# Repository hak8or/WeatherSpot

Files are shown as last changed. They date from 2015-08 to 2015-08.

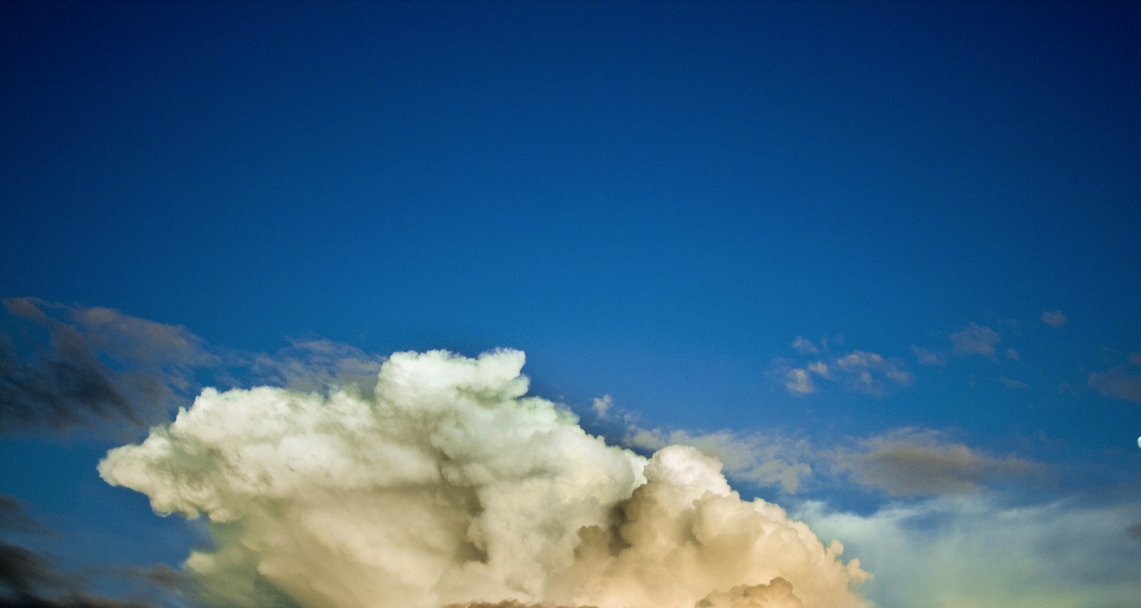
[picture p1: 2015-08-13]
Website/pic/sky_background.jpeg

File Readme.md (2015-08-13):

## WeatherSpot

A weather reporting ecosystem consisting of a website, windows native application, and multiple weather sensors to fetch weather data.

### Development
1. Login to the WeatherSpot server using ```ssh root@WeatherSpot.us```.
2. Make sure the influx database is running using ```docker ps -a``` to see active containers. If it's not running, a ```docker start weather_db``` will get it up again.
3. Do whatever you need to do.

In the event the influxdb container was removed, the following will get it up again:
```bash
docker run -d -p 8083:8083 -p 8084:8084 -p 8086:8086 -e PRE_CREATE_DB="weather" --name weather_db tutum/influxdb:latest
```

### Docker Installation
```bash
# Have to use this script since the official repo has an outdated (v1.5) docker.
wget -qO- https://get.docker.com/ | sh

# Unmasks the services.
systemctl unmask docker.service
systemctl unmask docker.socket

# And starts them.
systemctl start docker.service
systemctl start docker.socket
```

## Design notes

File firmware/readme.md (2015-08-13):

## Firmware for Weatherstation

Using an ESP8266 for communication over wifi to our backend hosted on digital ocean, log and send weather data to the "cloud".

### Doxygen docs
Running ```doxygen doxygen_config``` suffices.

### Compiling
Make sure to install the following libraries:
- DHT Sensor Library by Adafruit (Version 1.1.1)
- Sparkfun MPL3115A2 by Sparkfun (Version 1.2.0)
- TimerOne by Jesse (Version 1.1.0)

Afterwards, simply compiling suffices.

### Configuration
There are only three defines in ```firmware.ino``` which need to be modified,
- SSID (SSID of the wifi network you want to connect to)
- password (Password of the wifi you want to connect to)
- location (Name of the dataseries you want to send data too)

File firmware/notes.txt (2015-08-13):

Make a sensors struct or class to hold all our sensor data which will be used for JSON data sent to our server.

AT+UART_DEF=9600,8,1,0,0
AT+UART_CUR=9600,8,1,0,0
AT+RST
AT+CWMODE=1
AT+CWJAP="OpenWrt","castle2004"
AT+CIFSR
AT+GMR

00170901

http://www.electrodragon.com/w/ESP8266
http://www.rei-labs.net/esp8266-connecting-to-internet/
http://electronut.in/an-iot-project-with-esp8266/
http://mcuoneclipse.com/2014/12/14/tutorial-iot-datalogger-with-esp8266-wifi-module-and-frdm-kl25z/
https://github.com/espressif/esp8266_at/wiki/TCPIP_at_0019000902
http://www.instructables.com/id/Blink-for-ESP8266-native-like-arduino-using-Window/step2/Upload-latest-firmware-SDK/
https://www.youtube.com/watch?v=QkZrrydLw-8
http://bbs.espressif.com/viewtopic.php?f=5&t=680
http://www.esp8266.com/viewtopic.php?f=6&t=1428
http://blog.electrodragon.com/cloud-updating-your-wi07c-esp8266-now/
http://tech.scargill.net/esp8266-busy-s/
http://tomeko.net/other/ESP8266/
http://kacangbawang.com/latest-at-firmware-for-esp8266-with-512k-flash/
https://github.com/pfalcon/esp-open-sdk

=========================
I have been fumbling around with trying to update my SFP module from "00170901" (AT-thinker Firmware) as given by "AT+GMR".

I tried to update using "AT+CIUPDATE" but got an Error after the fourth step instead of OK, so I tried to do it manually using flash_download_tool_v1.2_150512, but I fear I really botched things up since now I get a "MEM CHECK FAIL" from the module, and pressing enter after a command using Putty just puts the cursor back at the beginning of the line instead of executing the command (such as AT+GMR).

I have attempted to flash the firmware using the most recent SDK (esp_iot_sdk_v1.2.0_15_07_03) as per [this](https://www.youtube.com/watch?v=QkZrrydLw-8) video, but I afterwards began to receive the memcheck error. I also attempted to flash the module as per the directions in the SDK readme but still same issue. I fear I probably overwrote some critical sections of flash and before botching things up further, I wanted to make sure I have an up to date resource.

So, does anyone know what files go to what locations from the most recent SDK so I can get my SFP-01 back up and running? Assume that I overwrote the entire flash with 0's, so I am starting from scratch. I wasn't sure if I should have posted this here or on the official [here](http://bbs.espressif.com/viewtopic.php?f=5&t=680).
=====================

### How to manually flash new SDK
esp_iot_sdk_v1.2.0\bin\at\eagle.flash.bin         0x00000
esp_iot_sdk_v1.2.0\bin\at\eagle.irom0text.bin     0x40000
esp_iot_sdk_v1.2.0\bin\blank.bin                  0x3e000
esp_iot_sdk_v1.2.0\bin\blank.bin                  0x7e000
esp_iot_sdk_v1.2.0\bin\esp_init_data_default.bin  0xFC000
26 Mhz crystal
40 MHZ SPI speed, Quad I/O, 4 megabit (SpiAutoSet probably does this automatically, need to check)
Now running at 115200 default, need to reset to lower speed because softserial sucks butt and can't keep up that fast. Reset to 9600 baud via AT+UART_DEF=9600,8,1,0,0

Also, putty does not offer to do a proper carriage return, so press enter and then ctrl-j after every command if you need to use putty. Suprisingly enough, the Arduino serial monitor has an option for newline and carriage return which works correctly.
http://comp.terminals.narkive.com/K5YqczS3/i-want-putty-to-send-a-linefeed-and-carriage-return-everytime-i-press-cr

### Output of GMR now.
AT+GMR

AT version:0.30.0.0(Jul  3 2015 19:35:49)
SDK version:1.2.0
compile time:Jul  3 2015 20:52:41

Pinout of wifi module:
TX -> RX
RX -> TX
CH_PD -> 3v3
VCC -> 3v3
GND -> GND
RST -> OPEN

pull RST down only for a second and let go, it will restart the module

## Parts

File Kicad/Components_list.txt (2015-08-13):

Components list

1. MPL3115A2 - Freescale Altimeter/pressure sensor. Digikey reference: MPL3115A2-ND. Price: $3.29 per unit
2. DHT11 - Digital Humidity Temperature Sensor. Price: $7.49 for 4 pieces
3. Light sensor. Price: free
4. Atmega328p - Main microcontroller Price: free
5. MCP1802 - Voltage Regulator - Digikey reference: MCP1802T-3302I/OTCT-ND. Price: free
6. Other - Subcomponents such as capacitors or resistors. Price: free
7. ESP8266 - Wifi module. Price:~$6? per unit

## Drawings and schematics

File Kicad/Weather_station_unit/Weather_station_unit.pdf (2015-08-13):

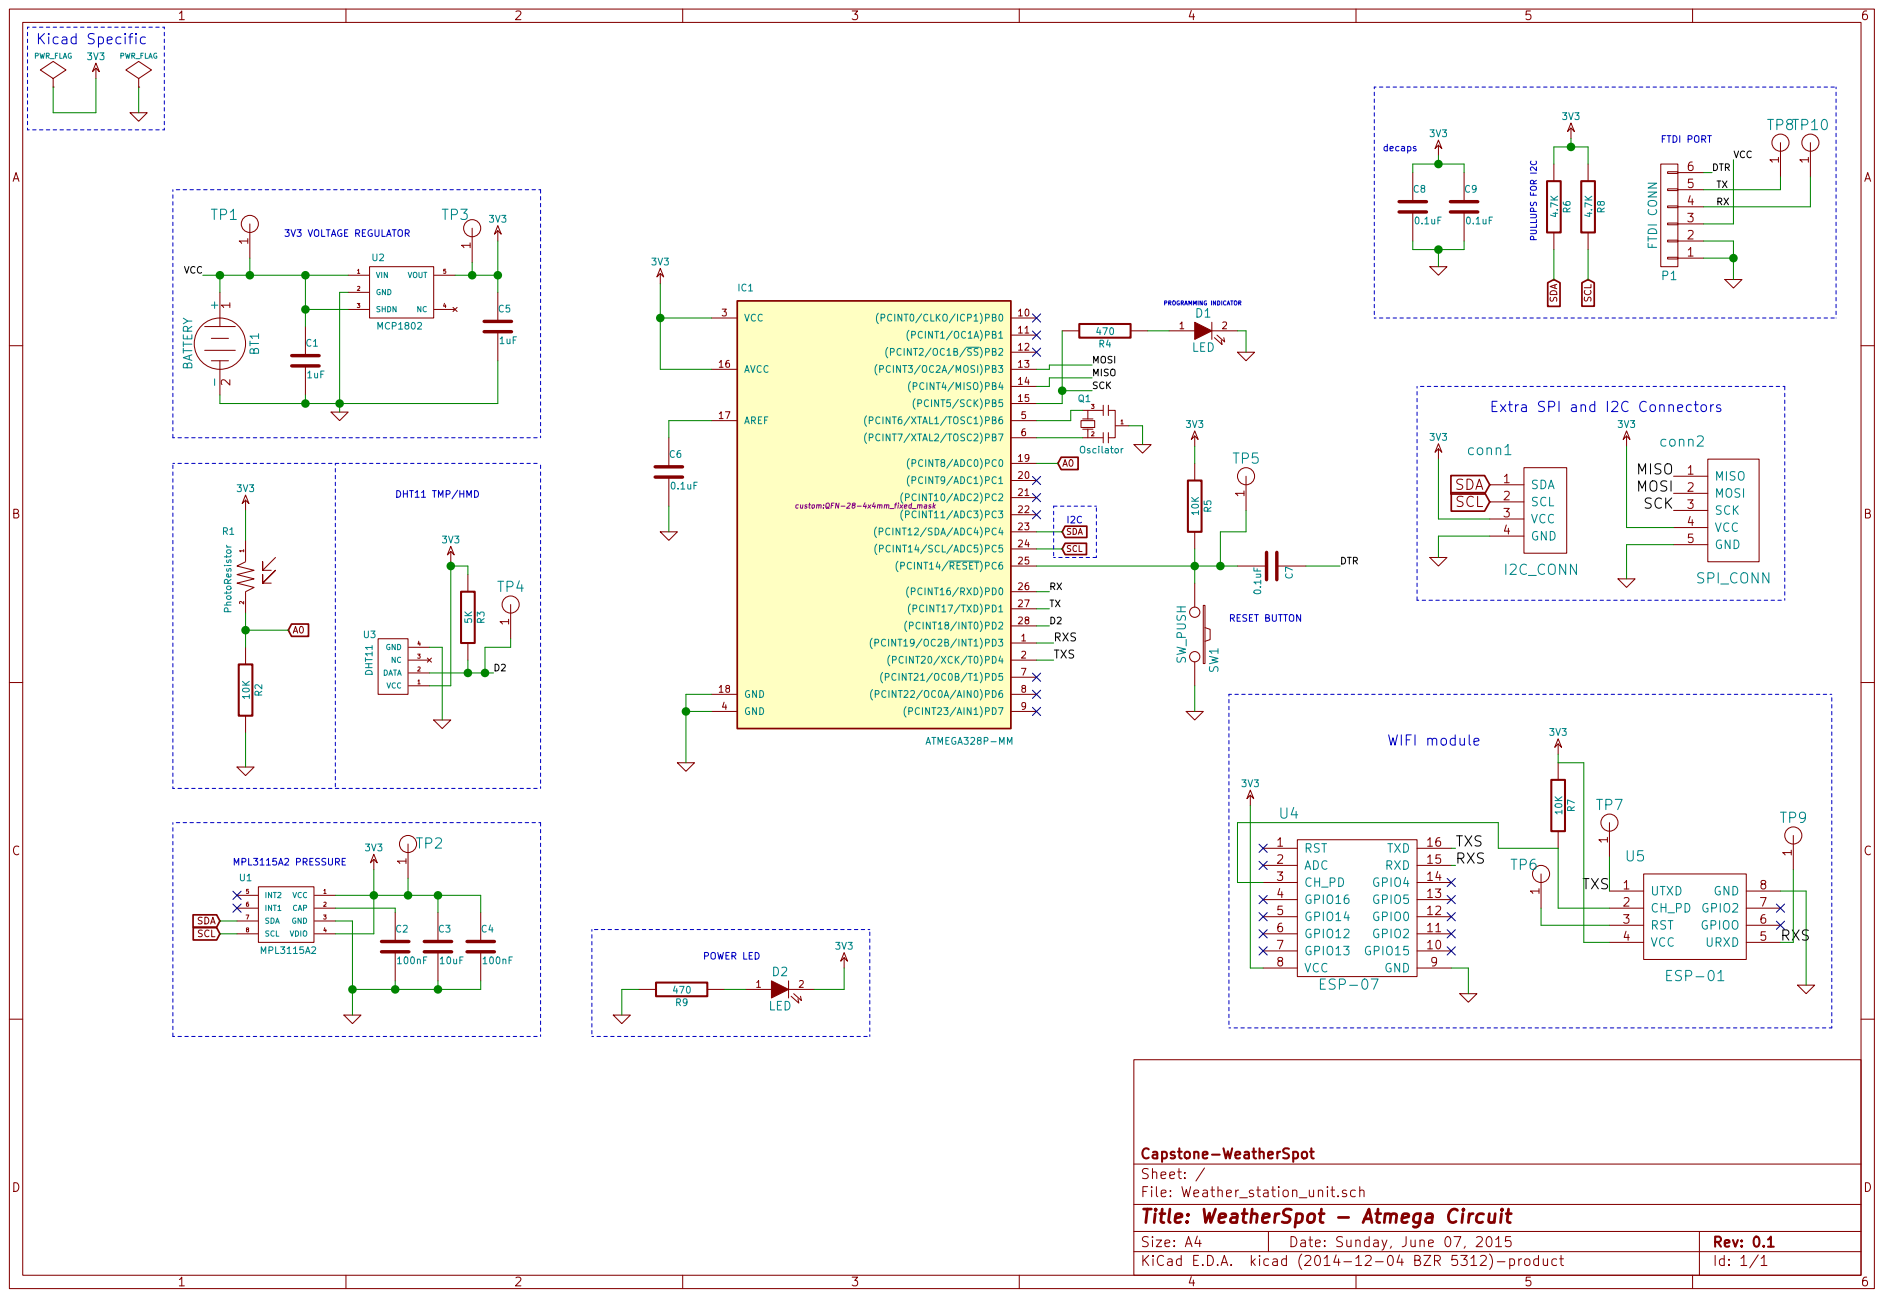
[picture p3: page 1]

1 TP10 MISO 1 MOSI 2 SCK 3 VCC 4 GND 5 conn2SPI_CONN
FTDI PORT

File: Weather_station_unit.sch Sheet: / Capstone-WeatherSpot

Id: 1/1 Title: WeatherSpot - Atmega Circuit

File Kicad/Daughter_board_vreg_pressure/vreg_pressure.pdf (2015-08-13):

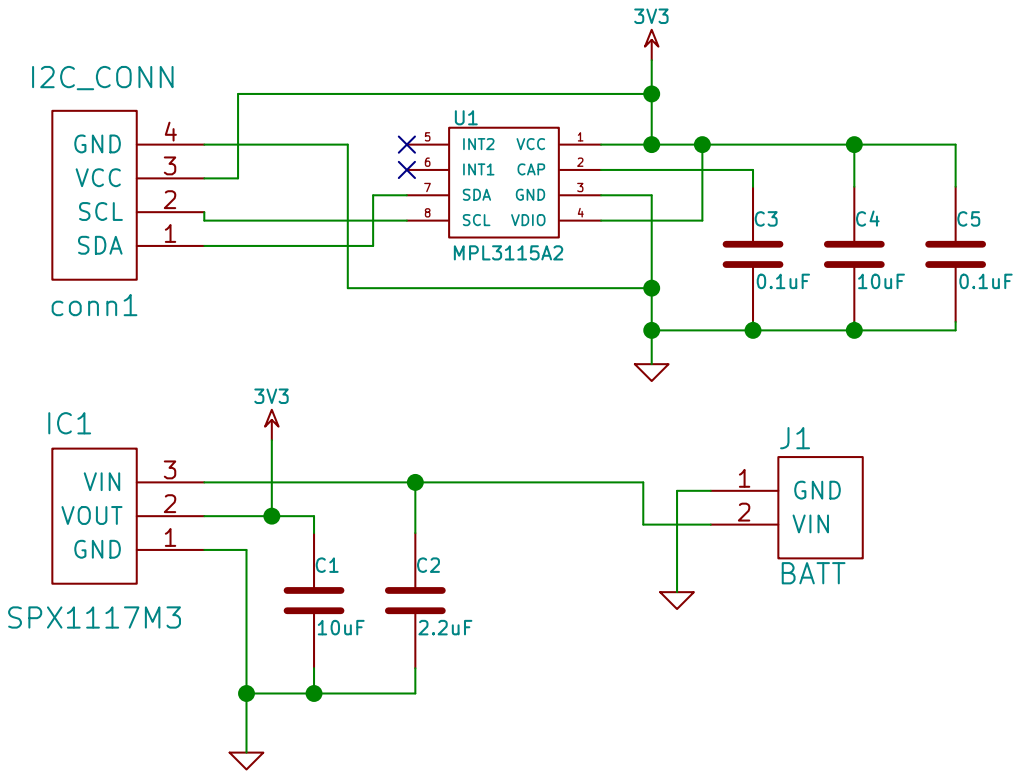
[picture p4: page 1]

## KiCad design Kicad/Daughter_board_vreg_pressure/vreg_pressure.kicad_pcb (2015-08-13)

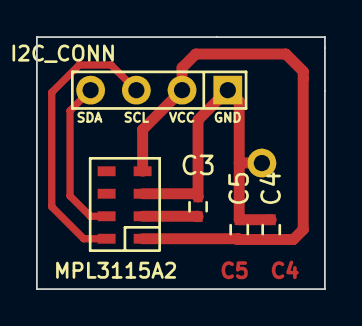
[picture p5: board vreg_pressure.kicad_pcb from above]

Board: 2 copper layers, 16.0 x 14.0 mm, 6 parts (0 on the bottom side), 5 nets.

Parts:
C3, C5: 0.1uF; C_0402
C4: 10uF; C_0402
U1: MPL3115A2
VIA_HOME_ETCH: VAL**; VIA_HOME_ETCH
conn1: I2C_CONN

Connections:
3V3: C4.1, C5.1, U1.1, U1.4, conn1.3
GND: C3.2, C4.2, C5.2, U1.3, VIA_HOME_ETCH.1, conn1.4
unnamed: C3.1, U1.2
unnamed: U1.7, conn1.1
unnamed: U1.8, conn1.2

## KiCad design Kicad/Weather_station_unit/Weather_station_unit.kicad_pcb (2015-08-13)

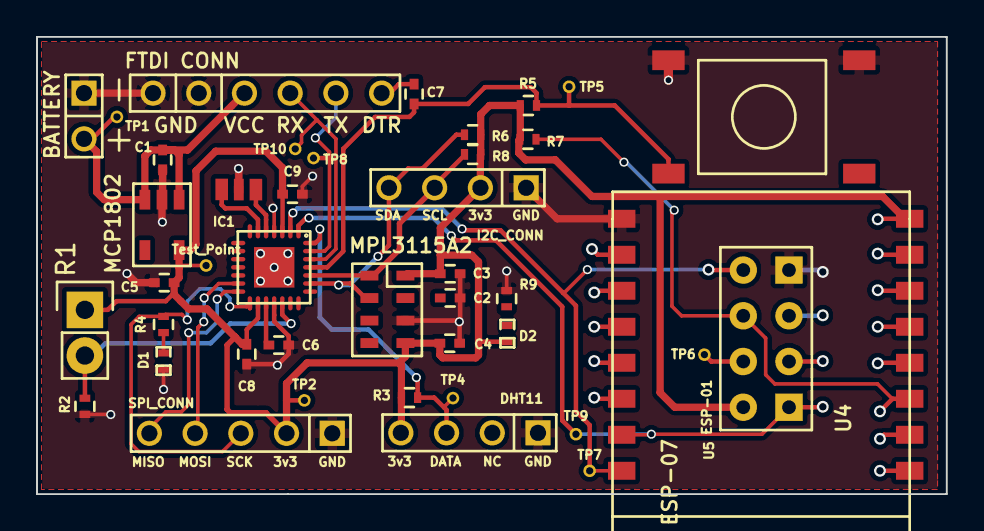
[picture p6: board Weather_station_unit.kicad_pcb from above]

Board: 2 copper layers, 50.5 x 25.4 mm, 42 parts (0 on the bottom side), 24 nets.

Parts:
BT1: BATTERY; BATT_CONN
C1, C5: 1uF; C_0402
C2, C4: 100nF; C_0402
C3: 10uF; C_0402
C6, C7, C8, C9: 0.1uF; C_0402
D1, D2: LED; SMD-0402_LED
IC1: ATMEGA328P-MM; QFN-28-4x4mm_fixed_mask
P1: FTDI CONN; FTDI_PORT
Q1: Oscilator; ceramic_resonator_smd
R1: PhotoResistor; Socket_Strip_Straight_1x02
R2, R5, R7: 10K; R_0402
R3: 5K; R_0402
R4, R9: 470; R_0402
R6, R8: 4.7K; R_0402
SW1: SW_PUSH; push_switch_SMD
TP1: TP1; TEST_POINT
TP2: TP2; TEST_POINT
TP3: Test_Point; TEST_POINT
TP4: TP4; TEST_POINT
TP5: TP5; TEST_POINT
TP6: TP6; TEST_POINT
TP7: TP7; TEST_POINT
TP8: TP8; TEST_POINT
TP9: TP9; TEST_POINT
TP10: TP10; TEST_POINT
U1: MPL3115A2
U2: MCP1802; MCP1802T
U3: DHT11
U4: ESP-07
U5: ESP-01
conn1: I2C_CONN
conn2: SPI_CONN

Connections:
3V3: C3.1, C4.1, C5.1, C8.1, C9.1, D2.2, IC1.3, IC1.16, R1.1, R3.1, R5.1, R6.1, R7.1, R8.1, TP2.1, TP3.1, U1.1, U1.4, U2.5, U3.1, U4.8, U5.4, conn1.3, conn2.4
/D2: IC1.28, R3.2, TP4.1, U3.2
/DTR: C7.1, P1.6
/MISO: IC1.14, conn2.1
/MOSI: IC1.13, conn2.2
/RX: IC1.26, P1.4, TP10.1
/RXS: IC1.1, TP9.1, U4.15, U5.5
/SCK: IC1.15, R4.2, conn2.3
/TX: IC1.27, P1.5, TP8.1
/TXS: IC1.2, TP7.1, U4.16, U5.1
/VCC: BT1.1, C1.1, P1.3, TP1.1, U2.1, U2.3
A0: IC1.19, R1.2, R2.1
GND: BT1.2, C1.2, C2.2, C3.2, C4.2, C5.2, C6.2, C8.2, C9.2, D1.2, IC1.4, IC1.18, P1.1, P1.2, Q1.1, R2.2, R9.2, SW1.2, U1.3, U2.2, U3.4, U4.9, U5.8, conn1.4, conn2.5
unnamed: C2.1, U1.2
unnamed: C6.1, IC1.17
unnamed: C7.2, IC1.25, R5.2, SW1.1, TP5.1
unnamed: D1.1, R4.1
unnamed: D2.1, R9.1
unnamed: IC1.5, Q1.3
unnamed: IC1.6, Q1.2
unnamed: R7.2, U4.3, U5.2
unnamed: TP6.1, U5.3
SCL: IC1.24, R8.2, U1.8, conn1.2
SDA: IC1.23, R6.2, U1.7, conn1.1

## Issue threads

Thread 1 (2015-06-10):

Add breakout for I2C, SPI, and UART on the PCB

hak8or, 2015-06-10:
For Kicad @glina126

glina126, 2015-06-11:
will do, as well as test points.

hak8or, 2015-06-11:
Just a cool thing, if you reference this in your commit, like
```bash
git commit -m "Added breakouts as per issue #1"
```

then the commit will be referenced in here. :sunglasses: And if you do ```bash fixes issue #1``` then it will even close the issue!

Closed 2015-06-11.

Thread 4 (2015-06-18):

Breakout GPIO 0 + 2 from wifi modules and 2 interrupt capable pins on Atmega

hak8or, 2015-06-18:
Considering issues regarding timers in hak8or@aeff93bcb327e73d56c7c01b92e3bbc12f4005ce, I feel it would be a good idea to break out two of the GPIO from the Wifi board and Arduino in the event the Arduino timers will be problamatic so we can still have the ability to generate timer based interrupts.

Since pulling down GPIO2 on the wifi module will cause it to enter firmware update mode, I recommend that the pins be just broken out in the form of a pair of 2 male headers.

hak8or, 2015-06-18:
The arduino people put the friggen onboard LED on the same pin as the SPI clock, so nevermind about the reason.

Though, it would be a good idea to break out two of the pins anyways if things go bad, especially from the Atmega at least considering it's a QFN.

Closed 2015-07-07.

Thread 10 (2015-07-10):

Create Custom Google Map Markers showing current condition and temperature values.

pl12133, 2015-07-10:
Example would be sunny, cloudy, raining, and fair condition icons with numbers over them.

I've got some basic ugly looking labels, [described here](http://blog.mridey.com/2009/09/label-overlay-example-for-google-maps.html), attached to the images now, it will take some styling to make them look decent. It might not be a great solution but its a start.

Closed 2015-12-18.

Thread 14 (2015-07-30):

Make responsive for Android

ple1213, 2015-07-30:
Responsive on desktop browser and apple but not on android.

http://stackoverflow.com/questions/12021794/android-browser-ignores-responsive-web-design

pl12133, 2015-08-01:
I've added few changes, give it a try on your Android devices now.
*Change 1*: Added a "min-height:100%" tag to html and body tags in `css/main_page.css`
*Change 2*: Set two content headers in our index.html.
`1 <meta content="True" name="HandheldFriendly">`
`2 <meta name="viewport" content="width=device-width, initial-scale=1.0, maximum-scale=1.0, user-scalable=0">`

The result is a background that seems to consistently fill the Viewport in both portrait and landscape on mobile devices.

I used http://www.cssmediaqueries.com and saw my device had a scale of 1.5, that was causing the scrollbars happening on Android devices. That stack overflow thread was very helpful, but has a little sillyness going on; Stefan K posts his answer of:
`1 <meta content="True" name="HandheldFriendly">`
`2 <meta name="viewport" content="width=device-width, initial-scale=1.0, maximum-scale=1.0, user-scalable=0">`
`3 <meta name="viewport" content="width=device-width">`

Line 1 and line 2 are the solution we need, and line 3 overwrites line 2, so removing line 3 provides us with the fix that we need. Fixing the scale back to 1.0 seems to fix the issue, but I'm not sure if changing scale like this has any other implications for our site.

Please test on any devices you have and see if these changes are in line with the goal of 'Responsive Web Design'

ple1213, 2015-08-04:
Works ok

hak8or, 2015-08-04:
Glorious, working here too. Though, one suggestion would be to remove the border around the graphs in the graph page. Since on my nexus 5 the graphs and whatnot get cut off.

[Imgur](http://i.imgur.com/jm0p3Rf.jpg)

hak8or, 2015-08-04:
Oh ffs the link doesn't seem to work, so here is the direct link. http://i.imgur.com/jm0p3Rf.jpg

Closed 2015-08-04.

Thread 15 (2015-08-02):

Heartbeat - messes up light readings

glina126, 2015-08-02:
The heartbeat, as great as it is, it is working against us here.

1, its using power - not much, but still. three hour battery life is not too long...
2. it is offsetting the light measurements.

Solution:
- reduce the blink rate
- blink only when not measuring the light intensity

hak8or, 2015-08-02:
The power consumption of heart beat is very low. I wouldn't even think about power consumption untill we can put the wifi module to sleep.

But what we could do is actually have it blink maybe once every 5 seconds with a 5% duty cycle or something like that. The chances of the light reading happening while the LED is active is 5% which is pretty small. Or continue at the speed now but make the duty cycle much smaller which would lead the same result.

glina126, 2015-08-02:
I am trying out disconnecting the wifi module from the AP, I will run a test to see if that helps preserve power.

hak8or, 2015-08-02:
Meaning the ```AT+CWQAP``` command? Did you try out the sleep command yet with the soldering fix?

Also, for sleep, to save you googling, it's ```AT+GSLP=500``` to make it sleep 500 milliseconds and then wake up by itself and start the ESP module again from scratch (just like after a reset state). But you have to solder "XPD_DCDC with EXT_RSTB via 0R" for this to work.

glina126, 2015-08-02:
yea i am doing the CT+CWQAP command for now. I will see how long this lives first. then I will try the AT+GSLP command - I really dont want to mess with soldering on the unit.

hak8or, 2015-08-02:
Soldering would be just shorting one of [these two pads](https://goo.gl/photos/3yqcSUxmTnHtEDG38) though (SMD module).

hak8or, 2015-08-07:
Alright, so I just flashed my board with the new firmware and will let it run for an hour and see how the light readings are. If it's good, I guess we can close this.

hak8or, 2015-08-10:
Closed since the heartbeat led is now disabled during sensor readings.

Closed 2015-08-10.

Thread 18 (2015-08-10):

Locations.html doesnt work properly

glina126, 2015-08-10:
locations.html has very strange spacing and it does not clear the old graphs when you switch to a new one. Instead it appends more and more graphs on the bottom with huge spacing.

pl12133, 2015-08-10:
That sounds like a broken version that I was working on but it has since been fixed, can you make sure that's not a cached copy? It was unstable like that before but `locations.html` should be working now.

hak8or, 2015-08-10:
Working totally fine on my end when mobile. I never noticed any spacing issues earlier, or that graphs were appended instead of replaced for locations.html

pl12133, 2015-08-13:
Fixed.

Closed 2015-08-13.

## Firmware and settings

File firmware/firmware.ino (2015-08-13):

// Gotta include this because the arduino IDE does some magic including nonsense.
#include <SoftwareSerial.h>
#include <Wire.h>

// Includes relevant to our project.
#include "Sensors.h"
#include "Heartbeat.h"
#include "Network.h"
#include "DHT.h"
#include <TimerOne.h>
#include "SparkFunMPL3115A2.h"

// Global because arduno says we need setup and loop functions.
Network network;
Sensors sensors;

// Defines for our wifi credentials.
#define SSID "OpenWrt"
#define password "castle2004"

// Defines what location (Series) we will be sending our data too.
#define location "Queens"

/**
 * @brief The main setup loop for our sensors and WIFI.
 */
void setup(){
	// Start up the serial communication.
	Serial.begin(115200);

	// Dump a decent header to our console.
	Serial.println(F("=================================================="));
	Serial.println(F("\t WeatherSpot firmware Uno-V1.0 RC1"));
	Serial.println(F("=================================================="));

	// Startup our network.
	while (!network.init_wireless(SSID, password)){
		Serial.println(F("Failed connecting to wireless network, retying in 3 seconds."));
		Heartbeat::panic();
		delay(3000);
	}

	// Startup a heartbeat LED.
	Heartbeat::start();

	// Extra delay for extra safety.
	delay(3000);

	// initiate DH11 sesnor at pin 2
	sensors.init_DH11(2);

	// Setup the pressure sensor.
	sensors.init_MPL3115A2();
}

/**
 * @brief Main loop of our application to read sensors and send data to server.
 */
void loop(){ 
	// time stamp each iteration
	Serial.println("\n\n************ loop() starting at millis: " + String(millis()) + " ************");

	// Make sure the LED doesn't interefere with light sensing.
	Heartbeat::stop();

	// Read our sensors.
	Sensors::Sensor_data sensor_data = sensors.read_sensors();

	// Dump the sensor data to our screen.
	sensors.print(sensor_data);

	// try to send 5 times, if 5 fail restart the module
	for(int attempt = 0; attempt < 5; attempt++){
		Serial.println("======== Data transmit attempt: [" + String(attempt) + "]/5");

		// Make LED panic if sending failed, attempt to reconnect to wifi on 2nd try.
		if(!network.send_packet(sensor_data, location)){
			// start panic mode
			Heartbeat::panic();

			// Reconnect to the WIFI, seems to make the WIFI module happier on the 2nd try.
			if(attempt == 2){
				while (!network.init_wireless(SSID, password)){
					Serial.println(F("Failed connecting to wireless network, retying in 3 seconds."));
					delay(3000);
				}

				// Extra delay for extra safety.
				delay(3000);
			}
		} else {
			// Make our heartbeat LED blink at a normal rate again if we were panicking earlier.
			Heartbeat::start();

			Serial.println(F("Sensor data was sent to the server succesfully!"));

			break;
		}
	}

	Serial.println(F("Waiting 1 min ...."));
	delay(60000);
}

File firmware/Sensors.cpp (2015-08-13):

#include "Heartbeat.h"
#include "Sensors.h"
#include <DHT.h>
#include "SparkFunMPL3115A2.h"

Sensors::Sensors(void){
	// This is arduino, and changing the compilation flags 
	// on a per project basis is nonexistant here, woooo!
	// Therefore, we can't use C++11, and nullptr.
	this->dht_module = NULL;
	this->pressure_sensor = NULL;
}

/**
 * @brief Just configures what pin our DH11 module uses for data.
 * 
 * @param data_pin Pin used for data communication.
 */
void Sensors::init_DH11(const uint8_t data_pin){
	dht_module = new DHT(data_pin, DHT11, 2);
	dht_module->begin();
}

/**
 * @brief Sets up the MPL3115A2 module for pressure readings.
 */
void Sensors::init_MPL3115A2(void){
	this->pressure_sensor = new MPL3115A2();

	// initiate the pressure sensor
	this->pressure_sensor->begin();

	// configure the pressure sensor
	pressure_sensor->setModeBarometer();
	pressure_sensor->setOversampleRate(7);
	pressure_sensor->enableEventFlags();
}

/**
 * @brief Reads sensor data.
 * 
 * @return Data from the reading in the form of a sensor_data struct.
 */
Sensors::Sensor_data Sensors::read_sensors(void){
	Sensors::Sensor_data sensor_data;

	// Check if this class was properly initiated.
	if (dht_module == NULL || pressure_sensor == NULL) {
		sensor_data.temperature_f = 0.0;
		sensor_data.humidity = 0.0;
		sensor_data.light = 0;
		sensor_data.pressure = 0.0;

		Heartbeat::panic();
		Serial.println(F("Attempt to read sensors before initilization."));

		return sensor_data;
	}

	// Read all our sensors.
	sensor_data.temperature_f = pressure_sensor->readTempF();
	sensor_data.humidity = dht_module->readHumidity();
	sensor_data.light = analogRead(A0);
	sensor_data.pressure = pressure_sensor->readPressure();

	return sensor_data;
}

/**
 * @brief Prints the contents of sensor data nicely over uart.
 * 
 * @param sensor_data The sensor data struct we will be displaying.
 */
void Sensors::print(const Sensors::Sensor_data sensor_data){
	Serial.print(F("-  Humidity: "));
	Serial.println(sensor_data.humidity);
	Serial.print(F("-  Temperature: "));
	Serial.println(sensor_data.temperature_f);
	Serial.print(F("-  Light: "));
	Serial.println(sensor_data.light);
	Serial.print(F("-  Pressure: "));
	Serial.println(sensor_data.pressure);
}

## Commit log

2015-06-07 Components List. This will expand as the schematics are made.
2015-06-07 Initialization of the kicad project
    [Weather_station_unit.kicad_pcb, Weather_station_unit.sch]
2015-06-07 Set the appropriate title, description and comments.
    [Weather_station_unit.sch]
2015-06-07 added custom footprints
2015-06-07 finished the initial atmega328p circuit
    [Weather_station_unit.sch]
2015-06-07 added a voltage regulator circuit
    [Weather_station_unit.sch]
2015-06-07 added a photoresitor circuit
    [Weather_station_unit.sch]
2015-06-07 added temperature/humidity circuit
    [Weather_station_unit.sch]
2015-06-07 added pressure circuit
    [Weather_station_unit.sch]
2015-06-08 final schematic clean up
    [Weather_station_unit.sch]
2015-06-08 PDF file for easier schematic viewing
2015-06-14 Added initial firmware with a heartbeat LED
2015-06-15 added wifi module
    [Weather_station_unit.sch]
2015-06-15 Cleaned up and added Test points in various locations for probing
    [Weather_station_unit.sch]
2015-06-15 added extra connections for SPI and I2C
    [Weather_station_unit.sch]
2015-06-15 updated the PDF to reflect the latest schematic changes
2015-06-15 annotated components
    [Weather_station_unit.sch]
2015-06-16 custom schematics components
2015-06-17 Added initial rough wired internet support.
2015-06-18 Added teensy support for heartbeat GPIO.
2015-06-18 Made heartbeat timer be 1 second but also added an interrupt to the timer via capture/compare ISR.
2015-06-18 Added stop functionality for heartbeat timer.
2015-06-20 switched website to bootstrap
2015-07-19 implemented sensors selection
2015-07-19 Added light reading sensor
2015-07-20 Changed pins for WIFI module serial comms to board pins
2015-07-20 Fixed find function and cleaned up commands for new ESP firmware.
    [Network.cpp]
2015-07-20 Fixed wifi IP address dump info
    [Network.cpp]
2015-07-20 Implimented heartbeat panic if connectivity goes wrong
    [Heartbeat.cpp, firmware.ino]
2015-07-20 Added check for if DHT module is not init correctly
    [Sensors.cpp]
2015-07-20 Fixed DHT11 module not working earlier
    [Network.cpp, Sensors.cpp]
2015-07-21 final components routing for version 0.2
    [Weather_station_unit.kicad_pcb]
2015-07-21 final schematics and net list
    [Weather_station_unit.sch]
2015-07-21 zipped gerber files of the v0.2 boards
2015-07-21 weatherspot components footprints
2015-07-21 added timerone.h library to the main folder - this way we can keep in sync
2015-07-21 fixed the led restart after panic mode
    [firmware.ino]
2015-07-24 Removed local copies of javascript and switched to CDN instead, cleaned up files.
2015-07-26 Initialized daughter board project
    [vreg_pressure.kicad_pcb, vreg_pressure.sch]
2015-07-26 finished the schematic for the daughter board
    [vreg_pressure.sch]
2015-07-26 added cap values and annotated the schematics
    [vreg_pressure.sch]
2015-07-26 net list and schematics finalized
    [$vreg_pressure.sch]
2015-07-26 pcb finalized
    [vreg_pressure.kicad_pcb]
2015-07-26 Updated constructor to make queryFactory more modular- a queryFactory is now constructed using a selector for an element to append queryFactory to, the text of the "Query Button" for querying, and th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
    Improved default time values when adding a new WHERE clause- upon clicking the "Add Where Clause" button the first two times will now create a query returning the last 24 hours of data.
    Added reset button to reset WHERE Clause textboxes, put a pink outline around the queryFactory area.
2015-07-27 Update "Use Query Factory" button
2015-07-28 final uncommitted fixes
    [vreg_pressure.sch]
2015-08-01 Added content headers for Viewport width scaling, added content header for HandheldFriendly; attempting to be responsive for all mobile devices. Added "Get Started" link to Google Maps page, centered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
2015-08-01 added support for the pressure sensor
2015-08-01 added light sensor to be pushed to server
2015-08-01 fixed pinout for the wifi module
    [Network.cpp]
2015-08-01 fixed connection issues when connecting to a new network
    [Network.cpp]
2015-08-01 small comment for the DH11 sensor being at pin 2
2015-08-02 if the send fails 3 times, the module will be restarted - prevents infinite loop
    [firmware.ino]
2015-08-03 fixed led off mode
    [Heartbeat.cpp]
2015-08-04 added the led off code in the proper spot
2015-08-04 Removed unused teensy code for heartbeat
2015-08-04 blink the led in sleep mode every 9 seconds for 1 second
2015-08-04 Moved MPl331 into sensors class
2015-08-04 power saver - such is life
2015-08-04 wall power dependent loop - seems to be super stable
2015-08-04 reconnect if we detect a problem wiht the send - if fails it will try again in 2 min
    [firmware.ino]
2015-08-05 Updated graph Y-axis scaling to be +/- 1% of the range
2015-08-05 Added ENTER button support for the queryFactory form
2015-08-05 Chained removes together to improve performance, fixed 'Reset' button handling
2015-08-07 take the temperature from a more sensitive sensor
2015-08-07 Changed query for graph, changed graph titles, increased number of ticks on x-axis, added styles to text element
2015-08-07 Changed container to insert graphs into, changed click event of markers to scroll down to graph section of page
2015-08-07 Increased margins to make 6 digit numbers fit along the y axis.
2015-08-10 Cleaned up loop startup serial print
2015-08-10 Made function for printing sensor data
2015-08-10 Added null set for pressure sensor in Sensors::Sensors()
2015-08-10 Cleaned up formatting for Sensors::read_sensors()
2015-08-10 Added serial print for succesfull data transmission
2015-08-10 Cleaned up print headers for network fails and info
    [Network.cpp]
2015-08-10 Moved sensor_data struct into Sensors class
2015-08-10 Removed unused data_pin Sensors data member
2015-08-10 Now using Arduino installed timerone lib instead of direct header
2015-08-10 Added filters by range for parameters to avoid outliers getting into the database
2015-08-10 Moved "Get Started" button
2015-08-11 removed the vreg and left the pressure sensor.
    [vreg_pressure.kicad_pcb]
